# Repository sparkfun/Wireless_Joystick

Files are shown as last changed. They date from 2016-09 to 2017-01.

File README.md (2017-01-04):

SparkFun Wireless Joystick Kit
=============================================

SparkFun Wireless Joystick Kit - Gamepad
SparkFun Wireless Joystick Kit - Dual Joysticks

[*SparkFun Wireless Joystick Kit (KIT-14051)*](https://www.sparkfun.com/products/14051)

What's in the kit:

* 1 - Wireless Joystick Board
* 2 - [Thumb Joysticks](https://www.sparkfun.com/products/9032)
* 2 - [Right Angle Momentary Push-Buttons](https://www.sparkfun.com/products/10791)
* 4 - [12mm Square Momentary Push Buttons](https://www.sparkfun.com/products/9190)

What's **not** in the kit:

* 1 - [Li-Ion battery](https://www.sparkfun.com/products/13851)
* 1 - [XBee](https://www.sparkfun.com/products/8665)

The SparkFun Wireless Joystick Kit is a customizable XBee wireless controller with a SAMD21 at the heart of the board. The controller can be configured in two ways; gamepad or dual-stick. The gamepad has a layout similar to the SNES gamepad, with a single joystick on the left and four push-buttons on the right, and two trigger buttons. The dual-stick configuration uses two analog joysticks, along with two trigger buttons. Dual joysticks are perfect for tank-steering robotics; the left joystick controls the motor(s) on the left side, and the right  joystick controls the motor(s) on the right side.
 
 Repository Contents
-------------------
* **/Hardware** - All Eagle design files (.brd, .sch)

Documentation
-------------------
* [**Hookup Guide**](https://learn.sparkfun.com/tutorials/wireless-joystick-hookup-guide)

License Information
-------------------
The hardware is released under [Creative Commons ShareAlike 4.0 International](https://creativecommons.org/licenses/by-sa/4.0/).
The code is beerware; if you see me (or any other SparkFun employee) at the local, and you've found our code helpful, please buy us a round!

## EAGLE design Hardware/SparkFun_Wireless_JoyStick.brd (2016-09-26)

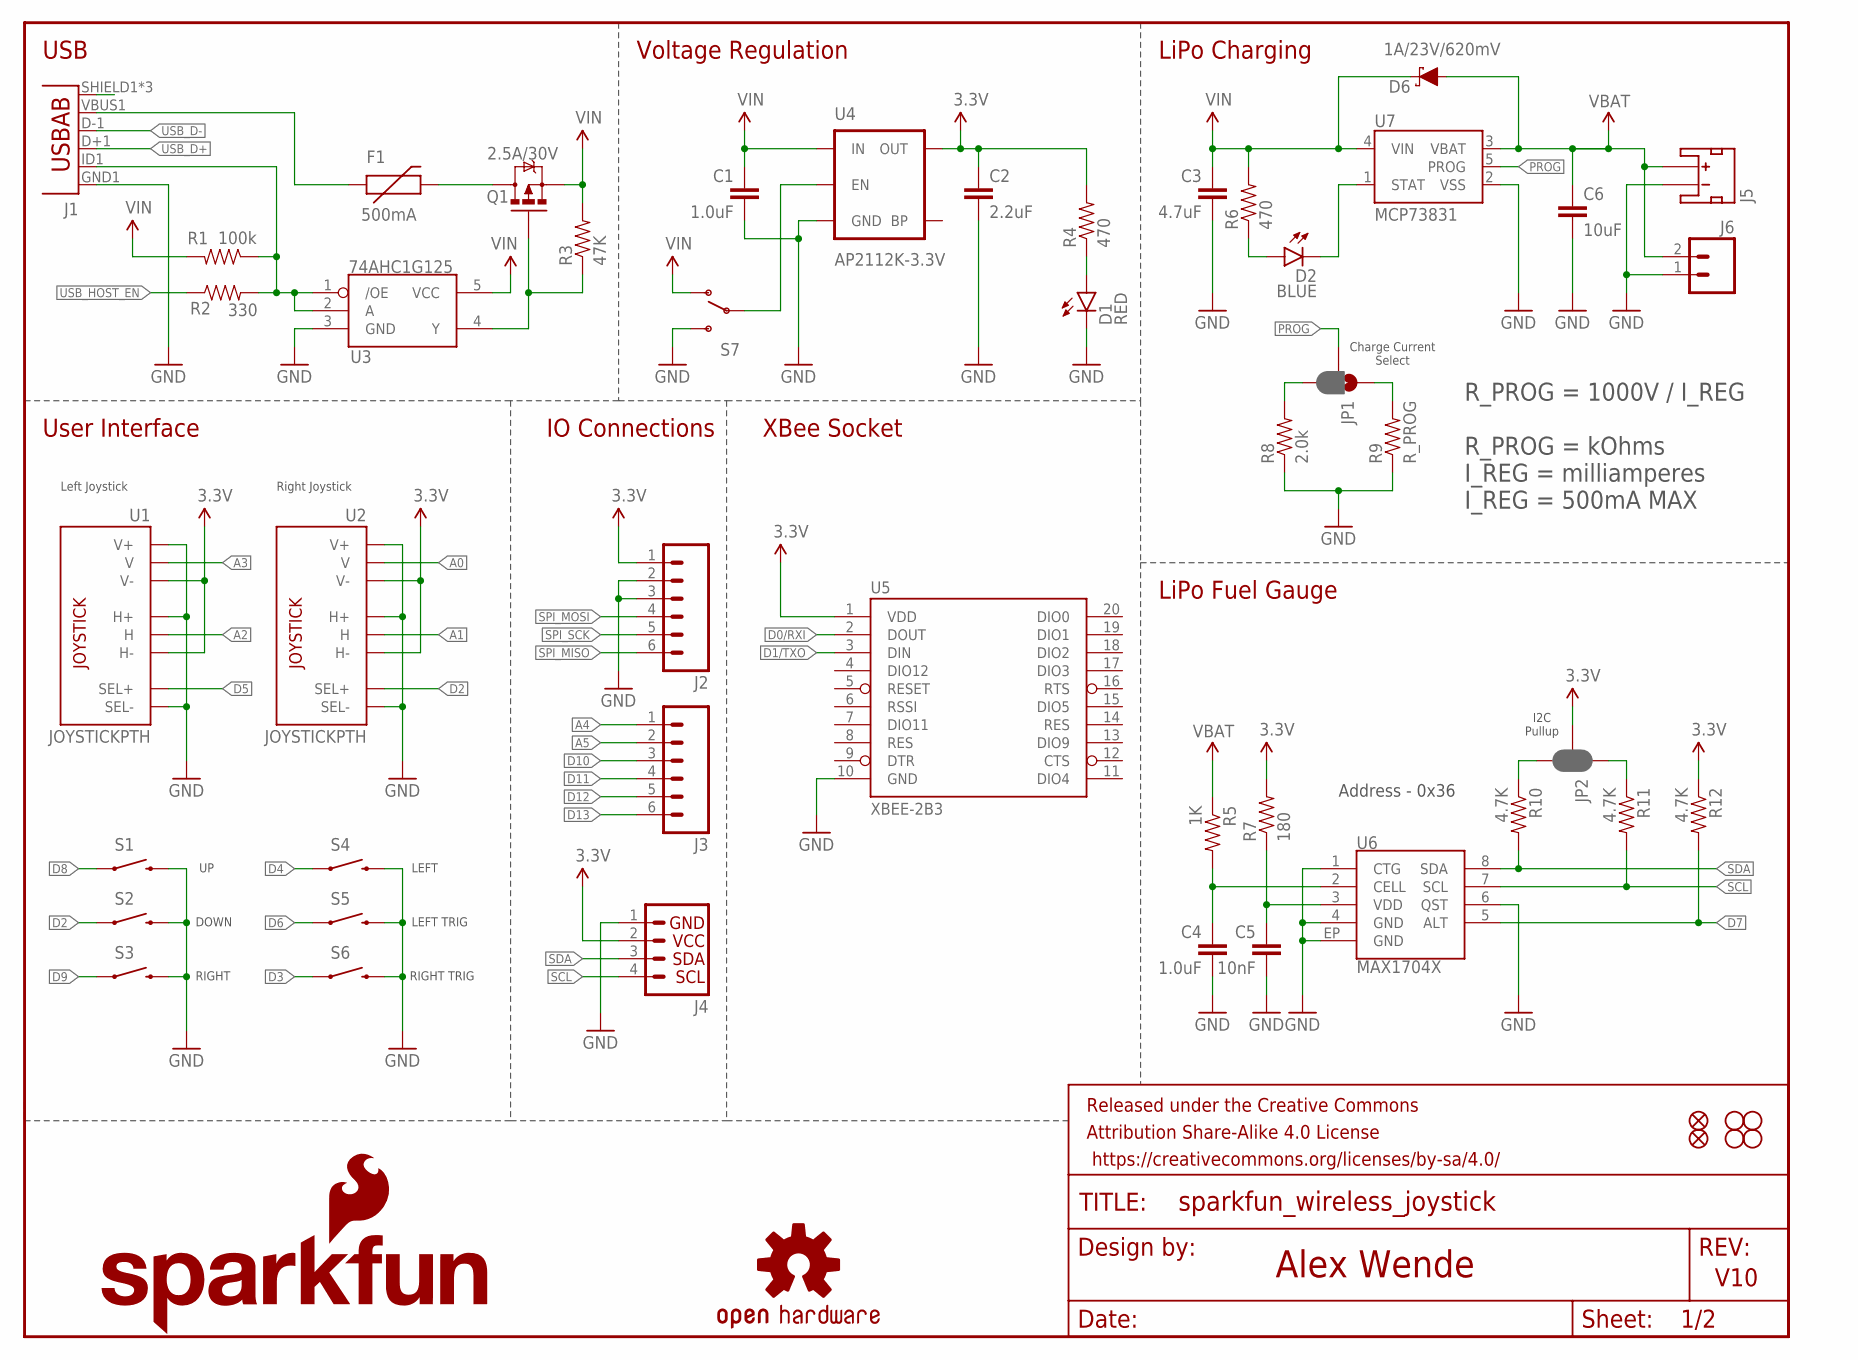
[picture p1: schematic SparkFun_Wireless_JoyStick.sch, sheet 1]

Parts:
C1: 1.0uF; 0805-CAP
C2: 2.2uF; 0603-CAP
C3: 4.7uF; 0603-CAP
C4: 1.0uF; 0603-CAP
C5: 10nF; 0603-CAP
C6: 10uF; 0603-CAP
D1: RED; LED-0603
D2: BLUE; LED-0603
D6: 1A/23V/620mV; SOD-323
F1: 500mA; PTC-1206
FD1, FD2: FIDUCIALUFIDUCIAL; MICRO-FIDUCIAL
FRAME1: FRAME-LETTER; CREATIVE_COMMONS
H1, H2, H3, H4: STAND-OFF
J1: USB-ABCONN-11794; USB-AB-MICRO-SMD_V03
J2, J3: M06NO_SILK_FEMALE_PTH; 1X06_NO_SILK
J4: I2C_STANDARD_NO_SILK; 1X04_NO_SILK
J5: JST_2MM_MALE; JST-2-SMD
J6: M021X02_NO_SILK; 1X02_NO_SILK
JP1: JUMPER-PAD-3-2OF3_NC_BY_PASTE; PAD-JUMPER-3-2OF3_NC_BY_PASTE_YES_SILK_FULL_BOX
JP2: JUMPER-PAD-3-NC_BY_PASTE; PAD-JUMPER-3-NC_BY_PASTE_YES_SILK_FULL_BOX
LOGO1: SFE_LOGO_NAME_FLAME.3_INCH; SFE_LOGO_NAME_FLAME_.3
LOGO2: OSHW-LOGOL; OSHW-LOGO-L
Q1: 2.5A/30V; SOT23-3@1
R1: 100k; 0603-RES
R2: 330; 0603-RES
R3: 47K; 0603-RES
R4, R6: 470; 0603-RES
R5: 1K; 0603-RES
R7: 180; 0603-RES
R8: 2.0k; 0603-RES
R9: R_PROG; AXIAL-0.4
R10, R11, R12: 4.7K; 0603-RES
S1, S2, S3, S4: SWITCH-MOMENTARY-212MM; TACTILE-PTH-12MM
S5, S6: SWITCH-MOMENTARY-2SIDE_EZ; TACTILE-PTH-SIDEEZ
S7: SWITCH_SPDT; KPS-1290
U1, U2: JOYSTICKPTH; JOYSTICK
U3: 74AHC1G125; SOT23-5
U4: AP2112K-3.3V; SOT23-5
U5: XBEE-2B3; XBEE-SMD
U6: MAX1704X; TDFN-8
U7: MCP73831; SOT23-5

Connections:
3.3V: C2.1, J2.1, J4.2, JP2.2, R4.2, R7.2, R12.1, U1.H3 (H-), U1.V3 (V-), U2.H3 (H-), U2.V3 (V-), U4.5 (OUT), U5.1 (VDD); also elsewhere on the board
A0: U2.V2 (V); also elsewhere on the board
A1: U2.H2 (H); also elsewhere on the board
A2: U1.H2 (H); also elsewhere on the board
A3: U1.V2 (V); also elsewhere on the board
A4: J3.1; also elsewhere on the board
A5: J3.2; also elsewhere on the board
D0/RXI: U5.2 (DOUT); also elsewhere on the board
D1/TXO: U5.3 (DIN); also elsewhere on the board
D2: S2.1, U2.B1A (SEL+); also elsewhere on the board
D3: S6.1; also elsewhere on the board
D4: S4.1; also elsewhere on the board
D5: U1.B1A (SEL+); also elsewhere on the board
D6: S5.1; also elsewhere on the board
D7: R12.2, U6.5 (ALT); also elsewhere on the board
D8: S1.1; also elsewhere on the board
D9: S3.1; also elsewhere on the board
D10: J3.3; also elsewhere on the board
D11: J3.4; also elsewhere on the board
D12: J3.5; also elsewhere on the board
D13: J3.6; also elsewhere on the board
GND: C1.2, C2.2, C3.2, C4.2, C5.2, C6.2, D1.C, J1.GND1 (GND), J2.2, J2.3, J4.1, J5.1 (-), J6.1, R8.1, R9.P$1 (1), S1.3 (2), S2.3 (2), S3.3 (2), S4.3 (2), S5.2, S6.2, S7.S, U1.B2A (SEL-), U1.H1 (H+), U1.V1 (V+), U2.B2A (SEL-), U2.H1 (H+), U2.V1 (V+), U3.3 (GND), U4.2 (GND), U5.10 (GND), U6.1 (CTG), U6.4 (GND), U6.6 (QST), U6.EP (GND), U7.2 (VSS); also elsewhere on the board
unnamed: JP2.1, R11.1
unnamed: JP2.3, R10.1
unnamed: JP1.1, R9.P$2 (2)
unnamed: F1.1, J1.VBUS1 (VBUS)
unnamed: C5.1, R7.1, U6.3 (VDD)
unnamed: S7.P, U4.3 (EN)
unnamed: F1.2, Q1.3 (D)
unnamed: J1.ID1 (USBID), R1.1, R2.2, U3.1 (/OE), U3.2 (A)
unnamed: C4.1, R5.2, U6.2 (CELL)
unnamed: JP1.3, R8.2
unnamed: D2.A, R6.1
unnamed: D2.C, U7.1 (STAT)
unnamed: D1.A, R4.1
unnamed: Q1.1 (G), R3.1, U3.4 (Y)
PROG: JP1.2, U7.5 (PROG)
SCL: J4.4, R11.2, U6.7 (SCL); also elsewhere on the board
SDA: J4.3, R10.2, U6.8 (SDA); also elsewhere on the board
SHIELD: J1.SHIELD1 (SHIELD), J1.SHIELD2 (SHIELD), J1.SHIELD3 (SHIELD)
SPI_MISO: J2.6; also elsewhere on the board
SPI_MOSI: J2.4; also elsewhere on the board
SPI_SCK: J2.5; also elsewhere on the board
USB_D+: J1.D+1 (D+); also elsewhere on the board
USB_D-: J1.D-1 (D-); also elsewhere on the board
USB_HOST_EN: R2.1; also elsewhere on the board
VBAT: C6.1, D6.A, J5.2 (+), J6.2, R5.1, U7.3 (VBAT)
VIN: C1.1, C3.1, D6.C, Q1.2 (S), R1.2, R3.2, R6.2, S7.O, U3.5 (VCC), U4.1 (IN), U7.4 (VIN)

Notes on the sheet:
User Interface
USB
LiPo Charging
Voltage Regulation
XBee Socket
R_PROG = 1000V / I_REG
R_PROG = kOhms I_REG = milliamperes I_REG = 500mA MAX
LiPo Fuel Gauge
Alex Wende
V10
Right Joystick
Left Joystick
DOWN
RIGHT
LEFT
LEFT TRIG
RIGHT TRIG
IO Connections
I2C Pullup
Charge Current Select
Address - 0x36

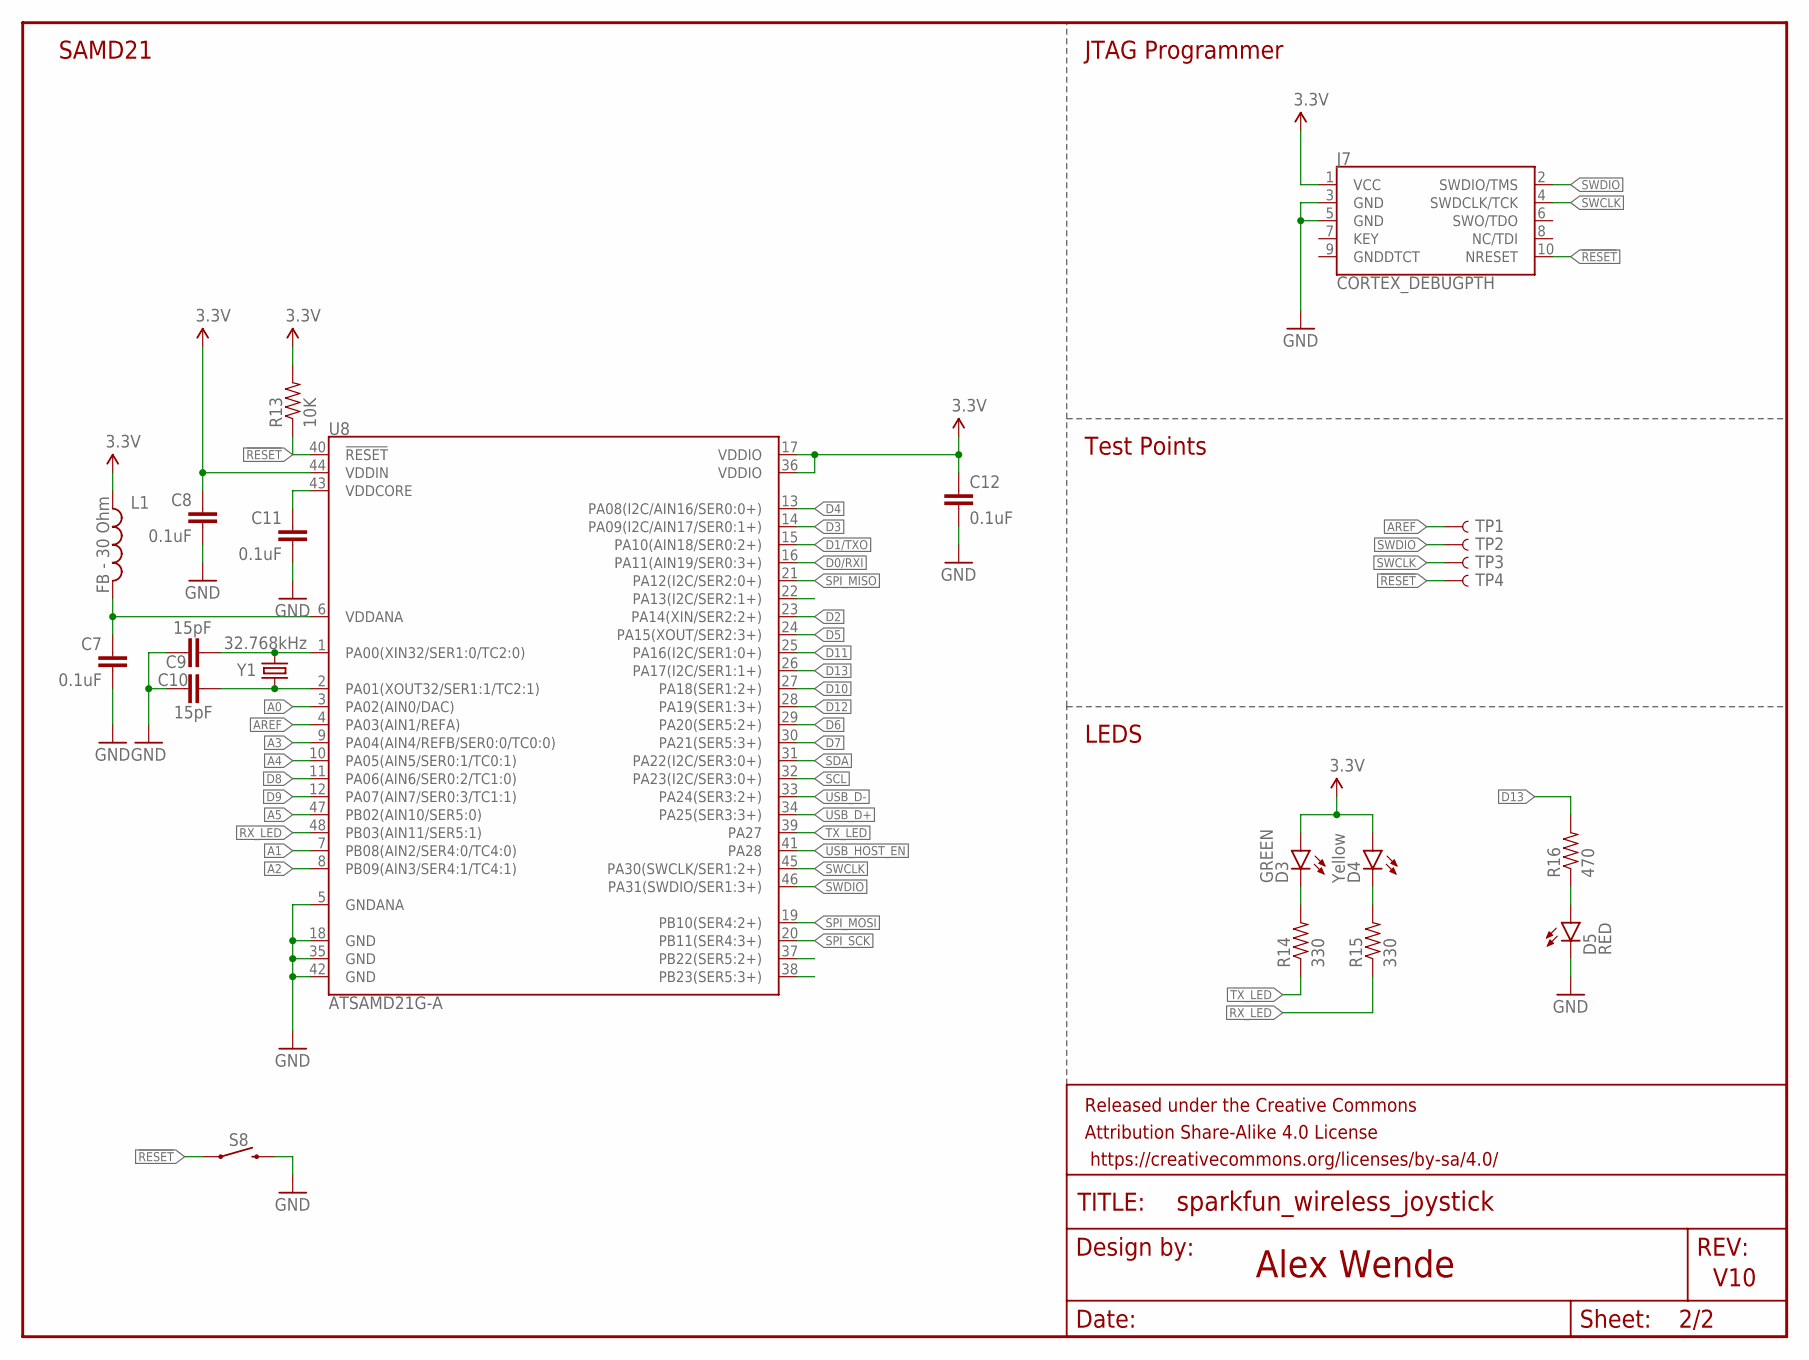
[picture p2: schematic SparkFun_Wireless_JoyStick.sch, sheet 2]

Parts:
C7, C8, C11, C12: 0.1uF; 0603-CAP
C9, C10: 15pF; 0603-CAP
D3: GREEN; LED-0603
D4: Yellow; LED-0603
D5: RED; LED-0603
FRAME2: FRAME-LETTERNO_PACKAGE; DUMMY
J7: CORTEX_DEBUGPTH; 2X5-PTH-1.27MM
L1: FB - 30 Ohm; 0603
R13: 10K; 0603-RES
R14, R15: 330; 0603-RES
R16: 470; 0603-RES
S8: MOMENTARY-SWITCH-SPST-SMD-4.6X2.8MM; TACTILE_SWITCH_SMD_4.6X2.8MM
TP1, TP2, TP3, TP4: TEST-POINT3; PAD.03X.03
U8: ATSAMD21G-A; TQFP-48
Y1: 32.768kHz; CRYSTAL-SMD-3.2X1.5MM

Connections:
3.3V: C8.1, C12.1, D3.A, D4.A, J7.1 (VCC), L1.1, R13.2, U8.17 (VDDIO), U8.36 (VDDIO), U8.44 (VDDIN); also elsewhere on the board
!RESET: J7.10 (NRESET), R13.1, S8.1, S8.2 (1), TP4.P$1, U8.40 (!RESET!)
A0: U8.3 (PA02(AIN0/DAC)); also elsewhere on the board
A1: U8.7 (PB08(AIN2/SER4:0/TC4:0)); also elsewhere on the board
A2: U8.8 (PB09(AIN3/SER4:1/TC4:1)); also elsewhere on the board
A3: U8.9 (PA04(AIN4/REFB/SER0:0/TC0:0)); also elsewhere on the board
A4: U8.10 (PA05(AIN5/SER0:1/TC0:1)); also elsewhere on the board
A5: U8.47 (PB02(AIN10/SER5:0)); also elsewhere on the board
AREF: TP1.P$1, U8.4 (PA03(AIN1/REFA))
D0/RXI: U8.16 (PA11(AIN19/SER0:3+)); also elsewhere on the board
D1/TXO: U8.15 (PA10(AIN18/SER0:2+)); also elsewhere on the board
D2: U8.23 (PA14(XIN/SER2:2+)); also elsewhere on the board
D3: U8.14 (PA09(I2C/AIN17/SER0:1+)); also elsewhere on the board
D4: U8.13 (PA08(I2C/AIN16/SER0:0+)); also elsewhere on the board
D5: U8.24 (PA15(XOUT/SER2:3+)); also elsewhere on the board
D6: U8.29 (PA20(SER5:2+)); also elsewhere on the board
D7: U8.30 (PA21(SER5:3+)); also elsewhere on the board
D8: U8.11 (PA06(AIN6/SER0:2/TC1:0)); also elsewhere on the board
D9: U8.12 (PA07(AIN7/SER0:3/TC1:1)); also elsewhere on the board
D10: U8.27 (PA18(SER1:2+)); also elsewhere on the board
D11: U8.25 (PA16(I2C/SER1:0+)); also elsewhere on the board
D12: U8.28 (PA19(SER1:3+)); also elsewhere on the board
D13: R16.2, U8.26 (PA17(I2C/SER1:1+)); also elsewhere on the board
GND: C7.2, C8.2, C9.1, C10.1, C11.2, C12.2, D5.C, J7.3 (GND), J7.5 (GND), S8.3 (2), S8.4 (2), U8.5 (GNDANA), U8.18 (GND), U8.35 (GND), U8.42 (GND); also elsewhere on the board
unnamed: D4.C, R15.2
unnamed: D5.A, R16.1
unnamed: D3.C, R14.2
unnamed: C11.1, U8.43 (VDDCORE)
unnamed: C9.2, U8.1 (PA00(XIN32/SER1:0/TC2:0)), Y1.P$2 (2)
unnamed: C10.2, U8.2 (PA01(XOUT32/SER1:1/TC2:1)), Y1.P$1 (1)
unnamed: C7.1, L1.2, U8.6 (VDDANA)
RX_LED: R15.1, U8.48 (PB03(AIN11/SER5:1))
SCL: U8.32 (PA23(I2C/SER3:0+)); also elsewhere on the board
SDA: U8.31 (PA22(I2C/SER3:0+)); also elsewhere on the board
SPI_MISO: U8.21 (PA12(I2C/SER2:0+)); also elsewhere on the board
SPI_MOSI: U8.19 (PB10(SER4:2+)); also elsewhere on the board
SPI_SCK: U8.20 (PB11(SER4:3+)); also elsewhere on the board
SWCLK: J7.4 (SWDCLK/TCK), TP3.P$1, U8.45 (PA30(SWCLK/SER1:2+))
SWDIO: J7.2 (SWDIO/TMS), TP2.P$1, U8.46 (PA31(SWDIO/SER1:3+))
TX_LED: R14.1, U8.39 (PA27)
USB_D+: U8.34 (PA25(SER3:3+)); also elsewhere on the board
USB_D-: U8.33 (PA24(SER3:2+)); also elsewhere on the board
USB_HOST_EN: U8.41 (PA28); also elsewhere on the board

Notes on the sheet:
Alex Wende
V10
SAMD21
JTAG Programmer
Test Points
LEDS

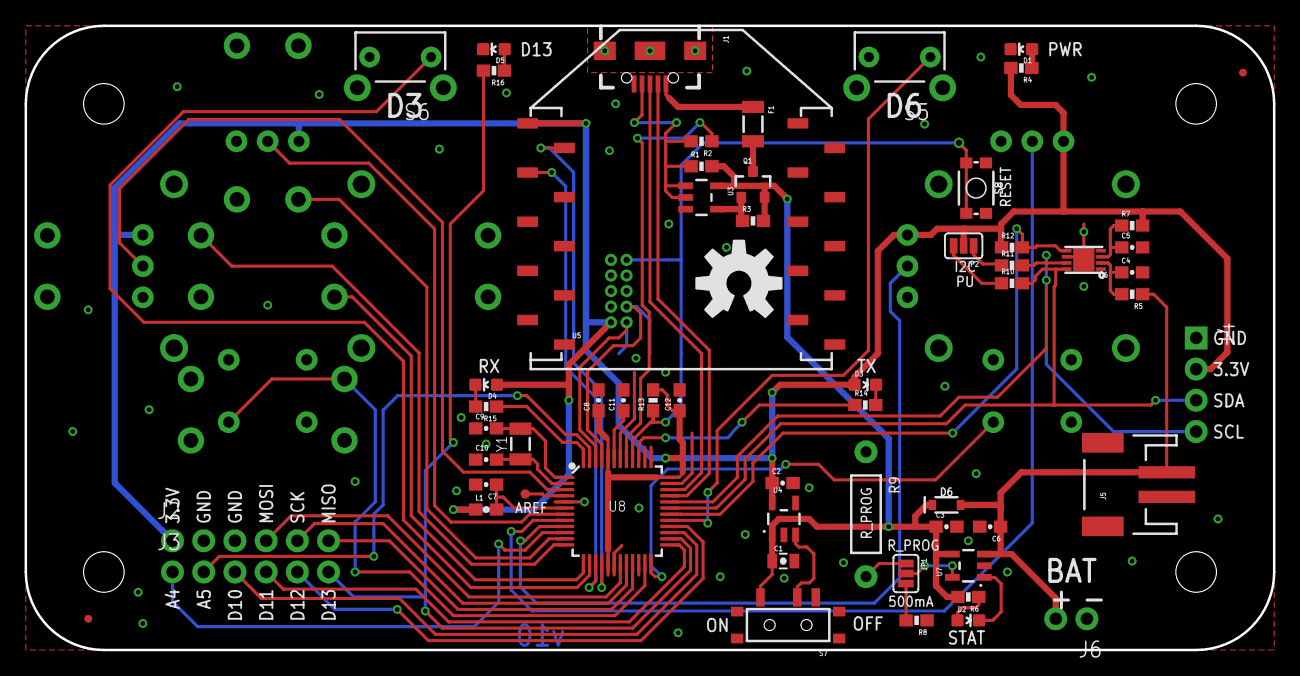
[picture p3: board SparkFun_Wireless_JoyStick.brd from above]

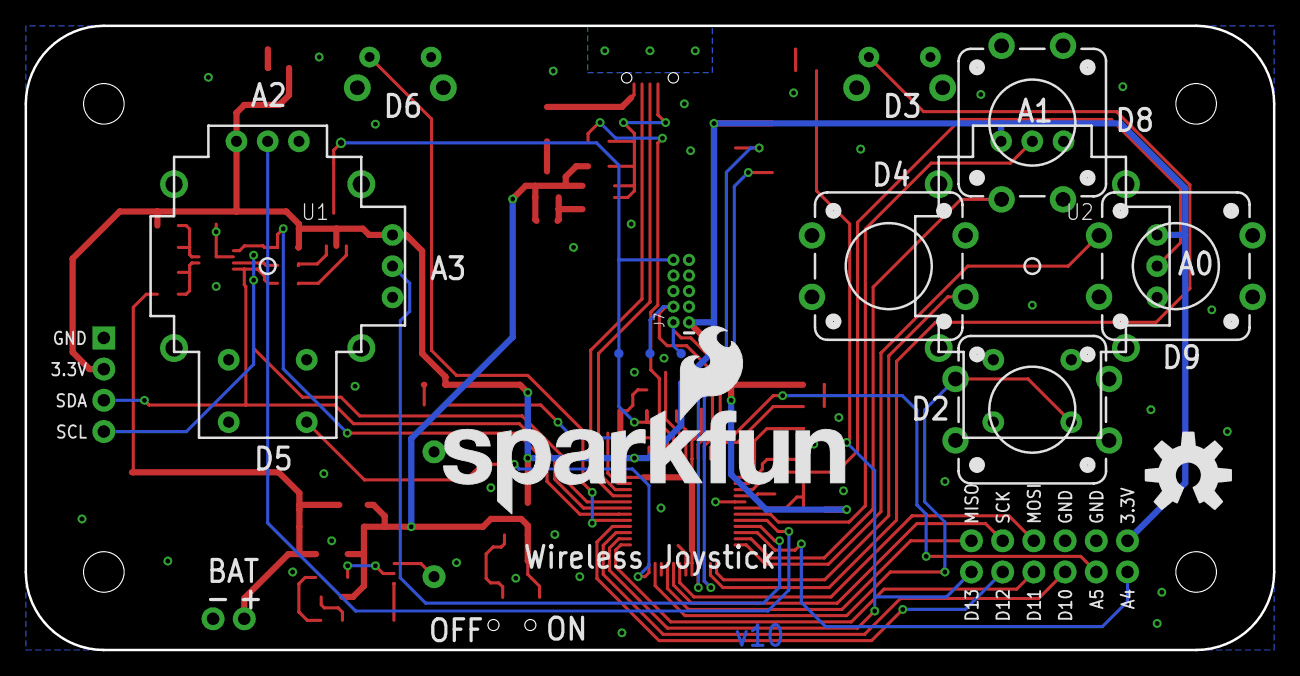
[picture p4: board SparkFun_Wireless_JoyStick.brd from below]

Board: 2 copper layers, 101.6 x 50.8 mm, 78 parts (12 on the bottom side), 61 nets.

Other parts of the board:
LOGO3: OSHW-LOGOL; OSHW-LOGO-L

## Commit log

2016-08-08 Initial Commit
    Adding Eagle files
    [SparkFun_Wireless_JoyStick.brd, SparkFun_Wireless_JoyStick.sch]
2016-08-09 V10 Updates
    - Broke out extra pins
    - Added LiPo fuel gauge
    - Added "trigger" buttons
    - Cleaned up layout
    [SparkFun_Wireless_JoyStick.brd, SparkFun_Wireless_JoyStick.sch]
2016-08-11 V10 update
    - Broke out a few more pins
    - Cleaned up the schematic
    [SparkFun_Wireless_JoyStick.brd, SparkFun_Wireless_JoyStick.sch]
2016-08-15 V10 Updates
    [SparkFun_Wireless_JoyStick.brd, SparkFun_Wireless_JoyStick.sch]
2016-08-16 Design Review Changes
    - Added LED to D13 for low batt indication.
    - Added test points for bootloader programming from testbed
    [SparkFun_Wireless_JoyStick.brd, SparkFun_Wireless_JoyStick.sch]
2016-08-16 Minor Changes
    Too minor to mention
    [SparkFun_Wireless_JoyStick.brd]
2016-08-19 QC Issues Fixed
    - TX_LED and RX_LED nets are now all 0.006" width
    - Version number changed to v01
    - IO connections use 3.3V and GND symbols instead of net labels
    - Replaced VBAT net label in LiPo Fuel Gauge with PWR symbol
    - Inductor PROD_ID updated to match SKU in Sparkle
    - Moved JTAG test points to bottom copper
    [SparkFun_Wireless_JoyStick.brd, SparkFun_Wireless_JoyStick.sch]
2016-09-22 Proto Changes
    - Added diode to allow powering the board from USB when no battery is
    present.
    - Switch now controls enable pin instead of VCC rail
    [SparkFun_Wireless_JoyStick.brd, SparkFun_Wireless_JoyStick.sch]
2016-09-22 Updating version to 10
    [SparkFun_Wireless_JoyStick.brd, SparkFun_Wireless_JoyStick.sch]
2016-09-22 Updating to version 10
    [SparkFun_Wireless_JoyStick.sch]
2016-09-23 Added fuel gauge i2c address
    [SparkFun_Wireless_JoyStick.sch]
2016-09-26 Minor Changes
    - added reset switch
    - reversed power and ground on joysticks
    [SparkFun_Wireless_JoyStick.brd, SparkFun_Wireless_JoyStick.sch]
2016-09-26 Moved gnd via
    Moved ground via that was too close to a trace
    [SparkFun_Wireless_JoyStick.brd]

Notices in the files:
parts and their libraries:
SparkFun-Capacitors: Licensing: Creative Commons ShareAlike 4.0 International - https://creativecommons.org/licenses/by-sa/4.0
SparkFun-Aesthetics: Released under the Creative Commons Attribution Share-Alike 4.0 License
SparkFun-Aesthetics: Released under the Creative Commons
